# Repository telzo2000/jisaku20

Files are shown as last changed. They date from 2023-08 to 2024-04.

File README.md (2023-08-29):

# jisaku20

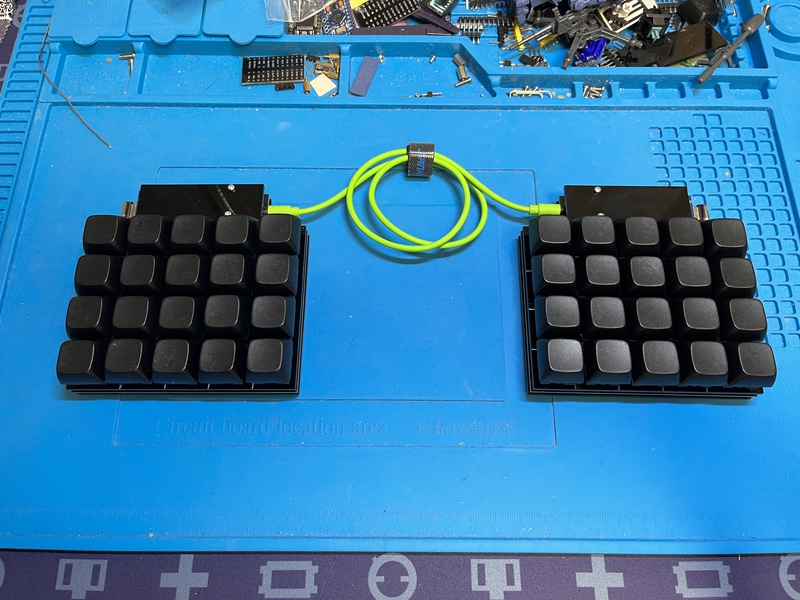
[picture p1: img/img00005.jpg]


jisaku20 is a 4x5 macro pad keyboard.
<br>
jisaku20は４×５のマクロパッドキーボードです。
<br><br>
By connecting jisaku20 and jisaku20_right with a TRRS cable, it becomes a 40-key split keyboard.Call it jisaku20x2.
<br>
jisaku20とjisaku20_rightをTRRSケーブルで繋ぐことにより、40キーの分割キーボードになります。それをjisaku20x2と呼びます。

<br>
<br>

## firmware

https://github.com/telzo2000/jisaku20/tree/main/firmware

## Case(acrylic plate)

https://github.com/telzo2000/jisaku20/tree/main/case_design

## Parts list

### jisaku20

| No. | Patrs | Quantity | remarks | Suppliers | Cost |
|--|--|--|--|--|--|
|番号|名前|数|備考|調達先|参考価格（送料込）|<br>
|1|PCB|1|20key ortho Layout|[elecrow](https://www.elecrow.com)<br>[JLCPCB](https://jlcpcb.com)<br>[ALLPCB](https://www.allpcb.com)|５枚で10〜20ドル|<br>
|2|Switch Plate|1||[elecrow](https://www.elecrow.com)|５枚で20〜30ドル|<br>
|3|Cover Plate|1|↑|↑|↑|<br>
|4|Bottom Plate|1|↑|↑|↑|<br>
|5|pro micro|1||[Talp Keyboard](https://talpkeyboard.net)|800円|
|6|Swith socket<br>スイッチソケット|20|cherry MX互換|[遊舎工房](https://yushakobo.jp)<br>[Talp Keyboard](https://talpkeyboard.net)<br>[Daily Craft Keyboard](https://shop.dailycraft.jp)等|10個で165円程度|
|7|Diode<br>ダイオード|20|リードタイプでもSMDでも可|[遊舎工房](https://yushakobo.jp)<br>[Talp Keyboard](https://talpkeyboard.net)<br>[Daily Craft Keyboard](https://shop.dailycraft.jp)等|100個で220円程度から|
|7|TRRS jack|1||[遊舎工房](https://yushakobo.jp)<br>[Talp Keyboard](https://talpkeyboard.net)<br>|１個55円|<br>
|8|リセット用タクトスイッチ|1||[遊舎工房](https://yushakobo.jp)<br>[Talp Keyboard](https://talpkeyboard.net)<br>|１個11円|<br>

※When using as jisaku20x2, the total number is doubled and a TRRS cable is required.
<br>
※jisaku20x2として使用する場合、すべての個数が２倍となり、さらに、TRRSケーブルが必要となります。
<br><br>
In addition, you will need a USB cable, keycaps, etc.
<br>
この他に、USBケーブル、キーキャップ等が必要です。
<br>

<br>

## Build guide

https://github.com/telzo2000/jisaku20/blob/main/buildguide_for_jisaku20.md

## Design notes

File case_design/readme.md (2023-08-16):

## Note

The case data is 2mm thick and 200mm long x 200mm wide.
<br>
ケースデータは厚み2mm、縦200mm×横200mmのサイズ。
<br>

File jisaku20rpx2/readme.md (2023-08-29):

# jisaku20rpx2

jisaku20rpx2

*A short description of the keyboard/project*

* Keyboard Maintainer: [m.ki](https://github.com/telzo2000)
* Hardware Supported: *The PCBs, controllers supported*
* Hardware Availability: *Links to where you can find this hardware*

Make example for this keyboard (after setting up your build environment):

    make jisaku20rpx2:default

Flashing example for this keyboard:

    make jisaku20rpx2:default:flash

See the [build environment setup](https://docs.qmk.fm/#/getting_started_build_tools) and the [make instructions](https://docs.qmk.fm/#/getting_started_make_guide) for more information. Brand new to QMK? Start with our [Complete Newbs Guide](https://docs.qmk.fm/#/newbs).

## Bootloader

Enter the bootloader in 3 ways:

* **Bootmagic reset**: Hold down the key at (0,0) in the matrix (usually the top left key or Escape) and plug in the keyboard
* **Physical reset button**: Briefly press the button on the back of the PCB - some may have pads you must short instead
* **Keycode in layout**: Press the key mapped to `QK_BOOT` if it is available

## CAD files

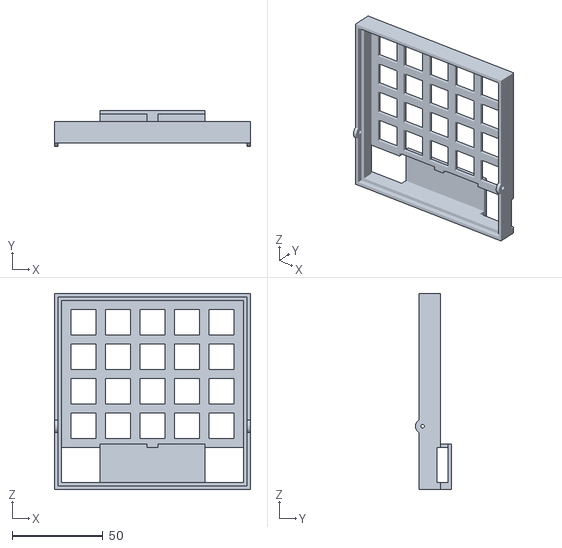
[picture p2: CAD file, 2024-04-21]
case_design/3D_print_case/sakurei_2/jisaku20rp_boxtype_bottomcase v3.stl
108.2 x 20.0 x 108.4

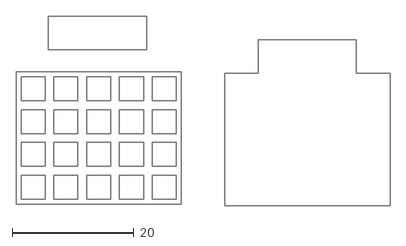
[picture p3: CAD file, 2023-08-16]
case_design/jisaku20_case/jisaku20_case.dxf
61.4 x 31.1

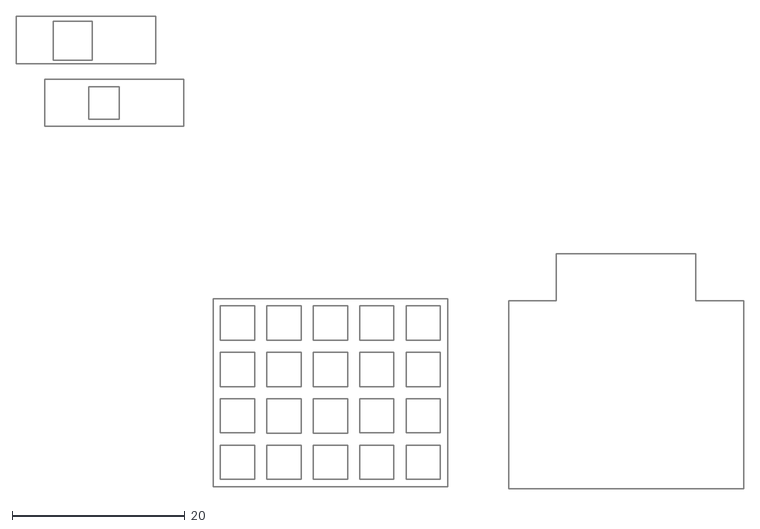
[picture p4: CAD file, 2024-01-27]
case_design/jisaku20_case2/jisaku20_case2.dxf
84.1 x 54.6

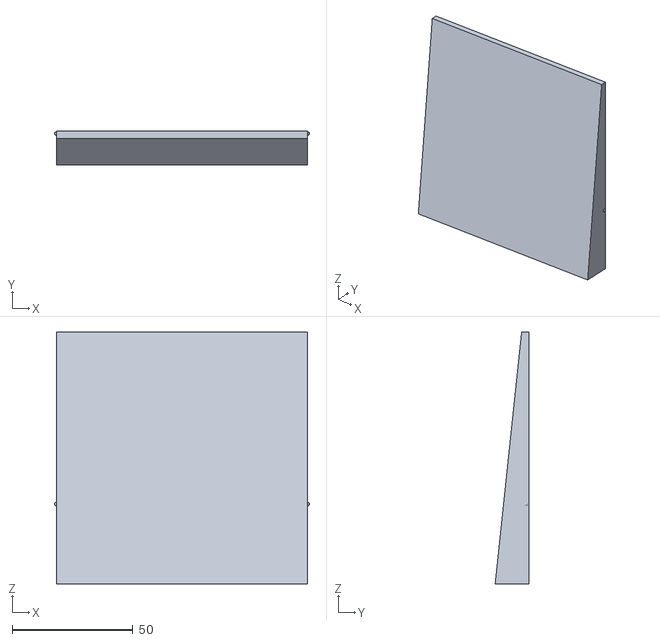
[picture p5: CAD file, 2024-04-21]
case_design/3D_print_case/sakurei_2/jisaku20rp_boxtype_topcase v5.stl
105.7 x 14.0 x 104.4

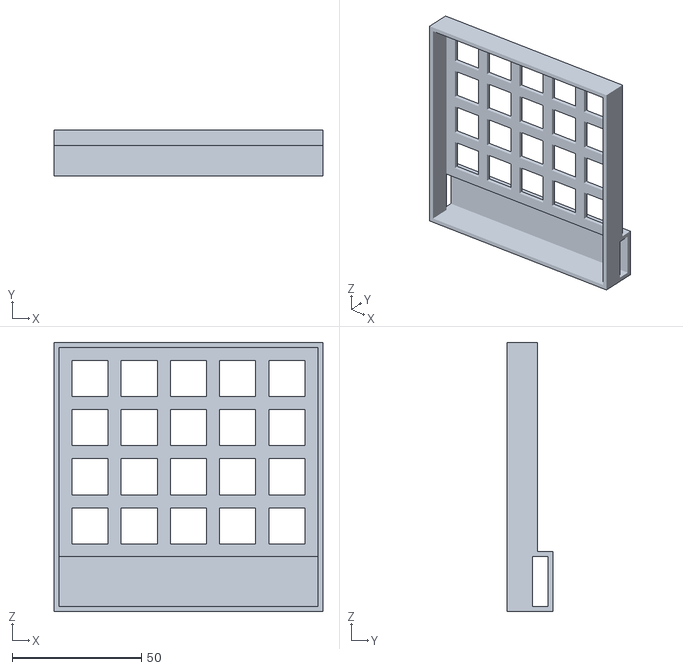
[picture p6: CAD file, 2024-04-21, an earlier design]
case_design/3D_print_case/sakurei_2/jisaku20rp_boxtype_topcase v2.stl
104.2 x 18.0 x 104.4

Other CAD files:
case_design/3D_print_case/sakurei_2/jisaku20rp_boxtype_bottomcase v2.stl

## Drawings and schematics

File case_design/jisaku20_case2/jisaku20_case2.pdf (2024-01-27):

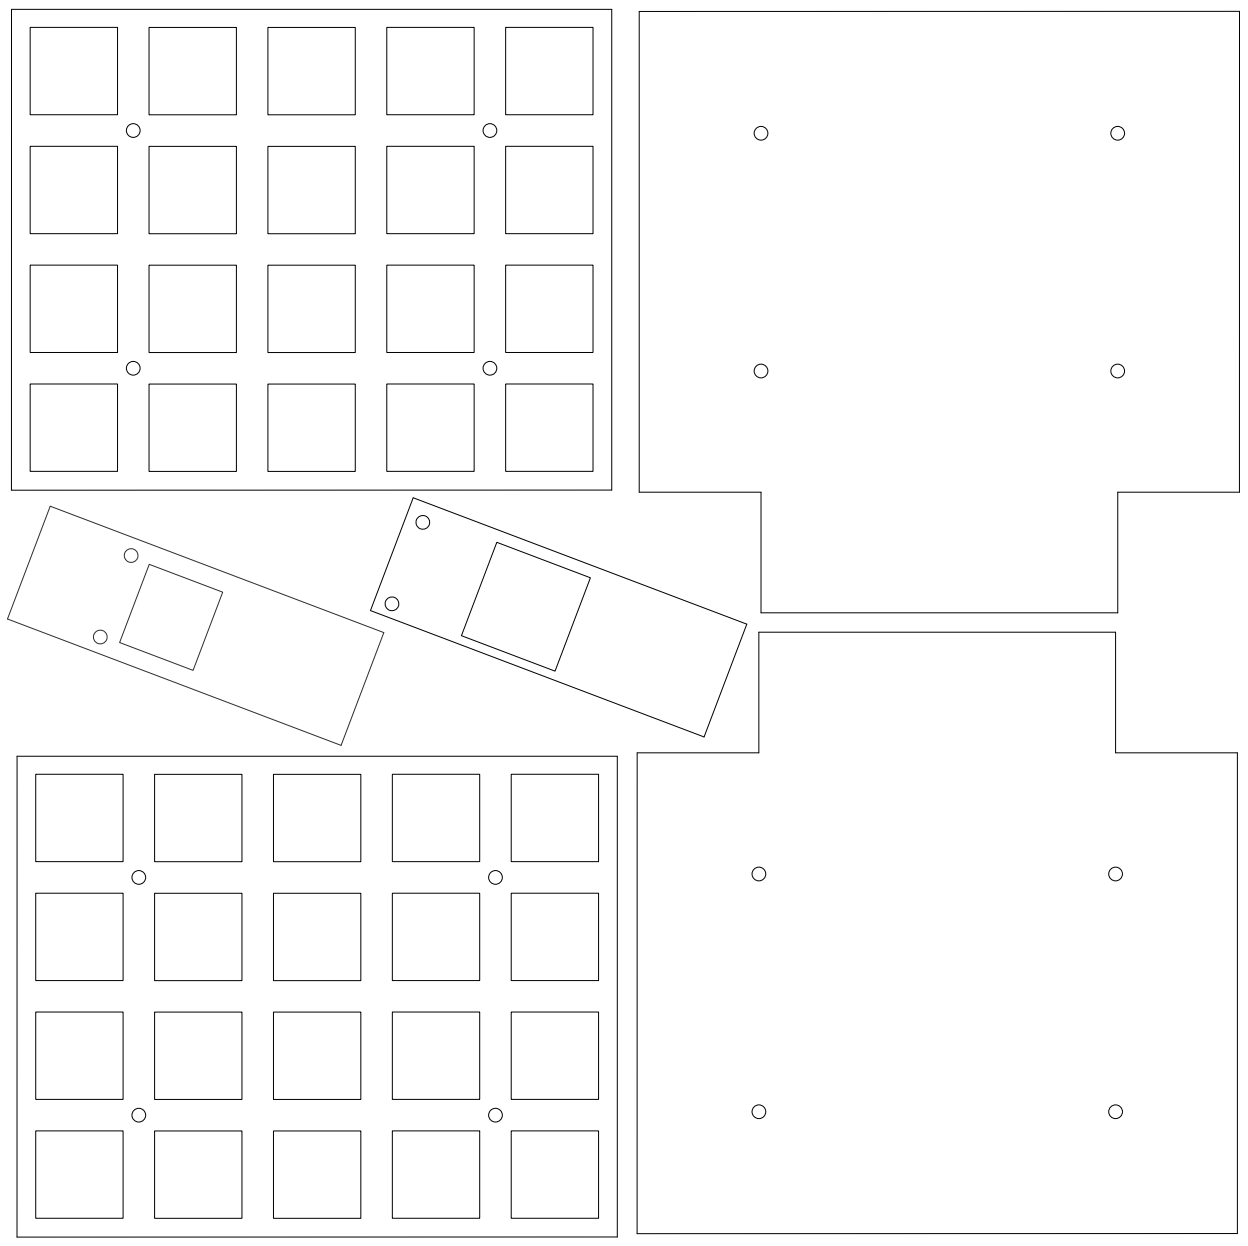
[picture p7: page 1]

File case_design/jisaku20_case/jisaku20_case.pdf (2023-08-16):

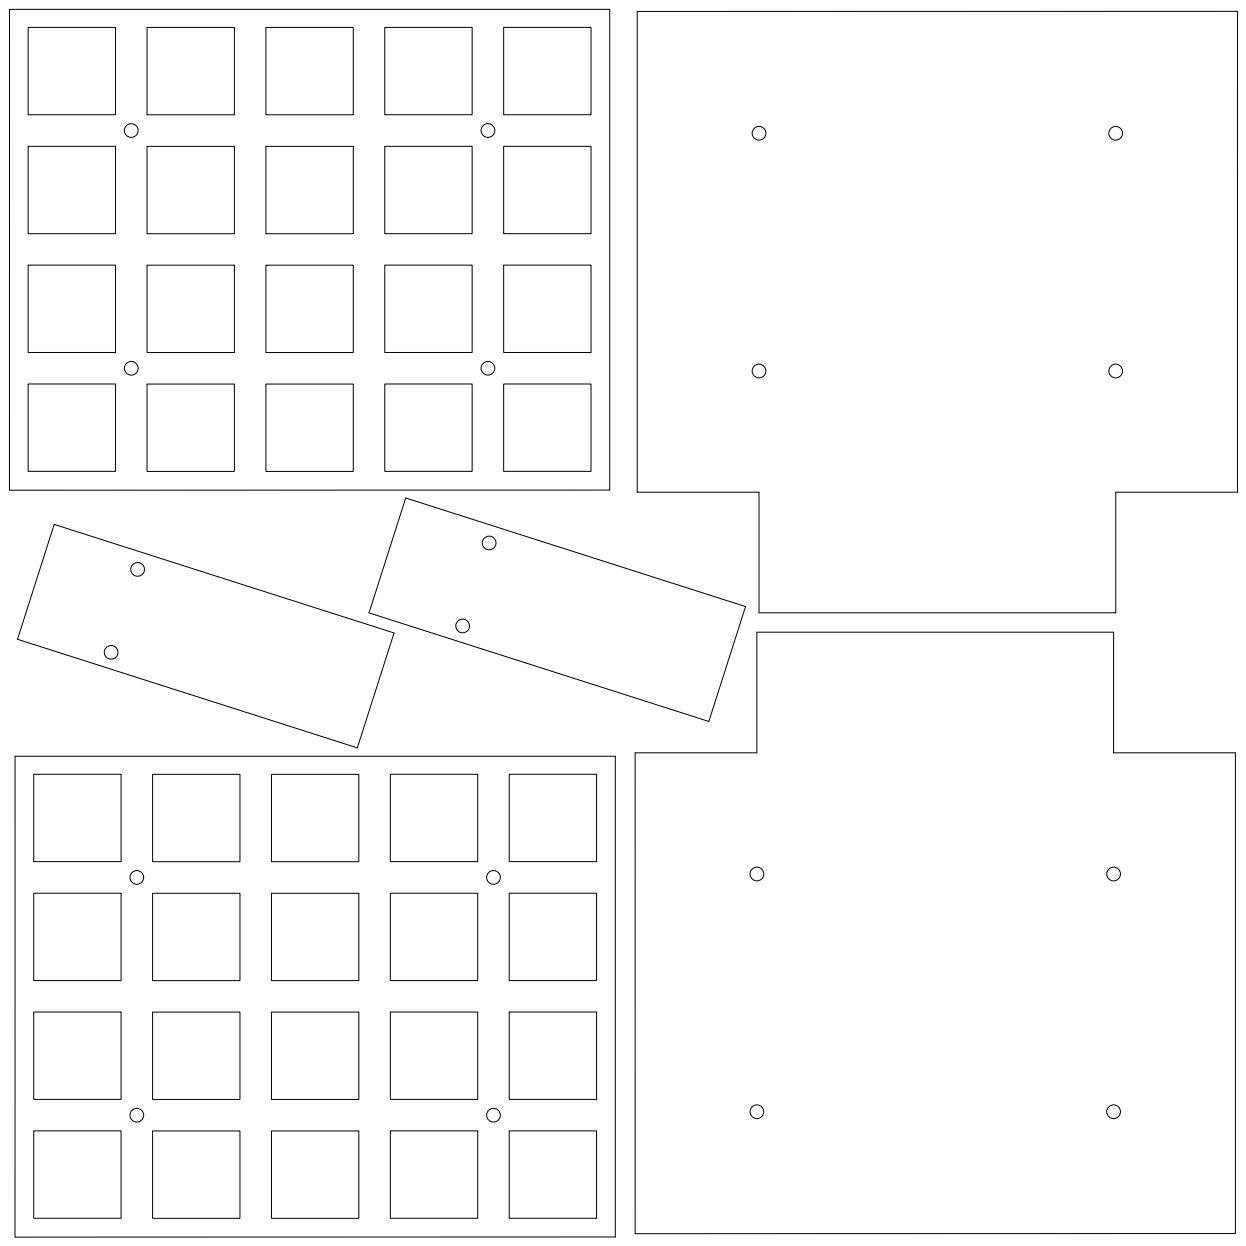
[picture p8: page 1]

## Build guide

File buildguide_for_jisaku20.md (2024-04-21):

# Build guide

## Firmware

###  QMK_FIRMWARE
[Here](https://github.com/telzo2000/jisaku20/tree/main/firmware)

<br>

参考<br>

https://github.com/telzo2000/Hello_keyboard/blob/main/readme_about_firmware.md

<br>

## Build 

### 1 Parts check

jisaku20 and jisaku20_right have a front side and a back side.
<br>
jisaku20及びjisaku20_rightには表面と裏面があります。
<br>

Front side

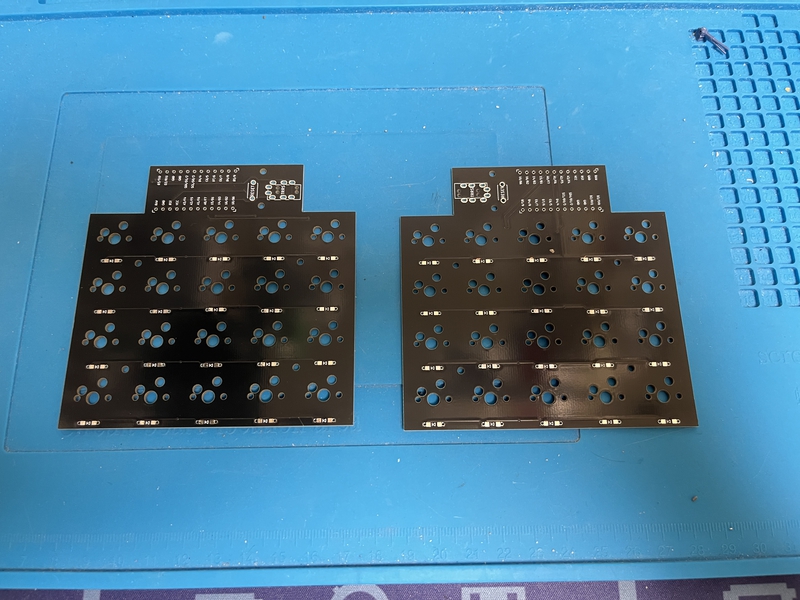
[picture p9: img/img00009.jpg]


Back side

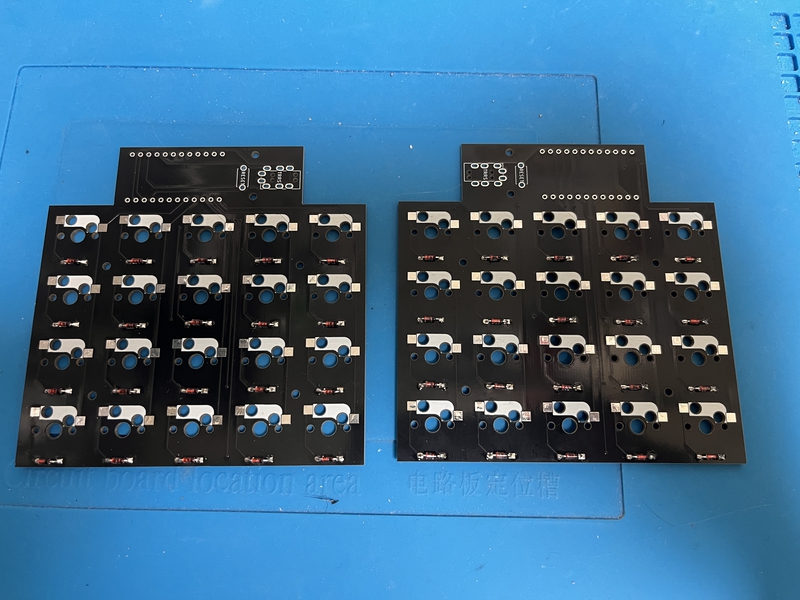
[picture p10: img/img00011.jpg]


<br>

### 2 Diode soldering

Note! "The diode's silk is wrong and sticks to the surface."
<br>
注意！　ダイオードのシルクが間違って、表面に付いています。
<br><br>

Solder the diodes to the back of each of the left and right.
<br>
左右それぞれの裏面にダイオードのハンダ付けをします。
<br>

There are lead type and SMD diodes.
<br>
ダイオードはリードタイプか、SMDがあります。
<br>
Here, we will explain the lead type soldering.
<br>
ここでは、リードタイプのハンダ付けの説明をします。
<br>

Use a lead bender to bend the legs of the diode.
<br>
リードベンダーを使い、ダイオードの足を曲げます。
<br>
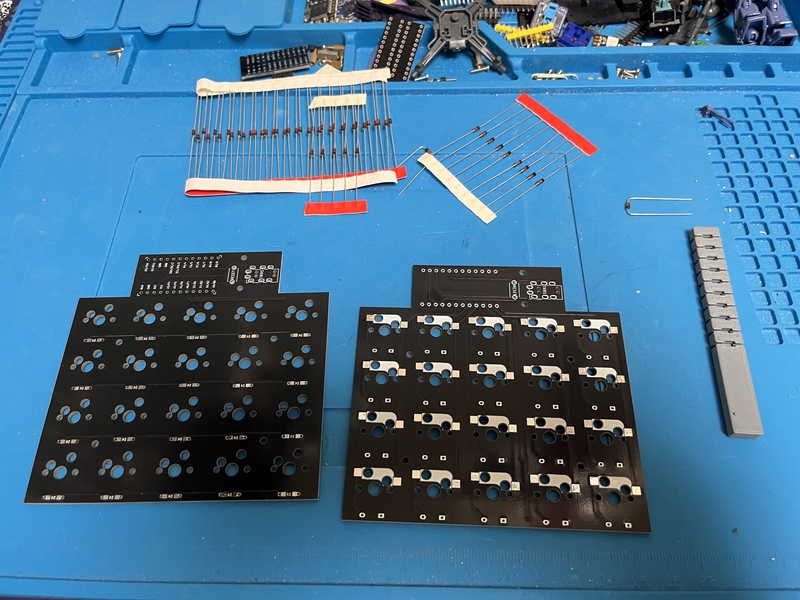
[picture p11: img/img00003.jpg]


Insert the diode into the board.
<br>
ダイオードを基板に挿しこみます。
<br>

Please pay attention to the orientation of the diode.
<br>
ダイオードの向きに注意してください。
<br>
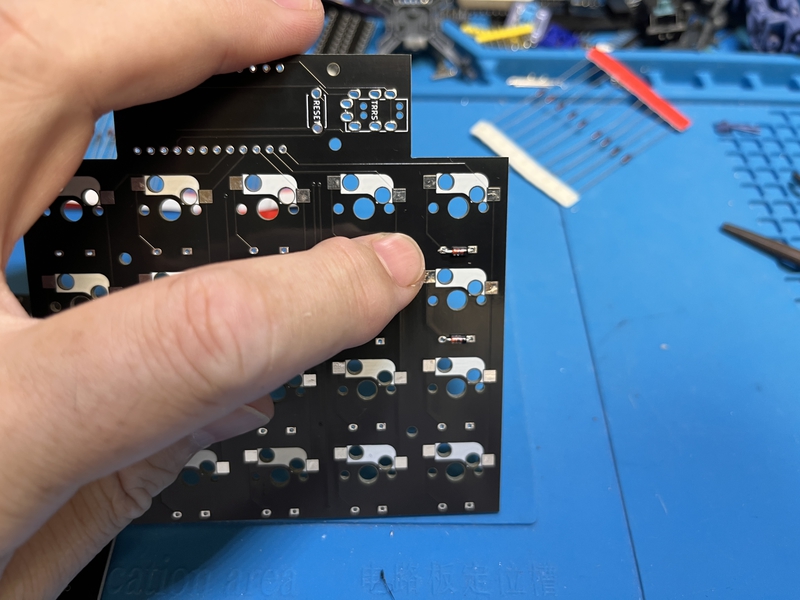
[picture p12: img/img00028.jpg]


Secure the diode with masking tape, then face up.
<br>
マスキングテープでダイオードを固定してから、表面を上にします。
<br>

Solder the protruding legs.
<br>
はみ出ている足部分に、ハンダ付けをします。
<br>
After soldering, use nippers to cut off the protruding legs.
<br>
はんだ付けが終わったら、はみ出ている足をニッパーで切り取ってください。
<br>


[８倍速　Diodeハンダ付け動画](https://youtu.be/Yaodh2-XxV4)

<br>
<br>

### 3 Soldering switch sockets

Solder the switch sockets on the back side.
<br>
裏面にスイッチソケットのハンダ付けをします。
<br>
Hold a little solder on the terminals.
<br>
端子に少しハンダを持ってください。
<br>

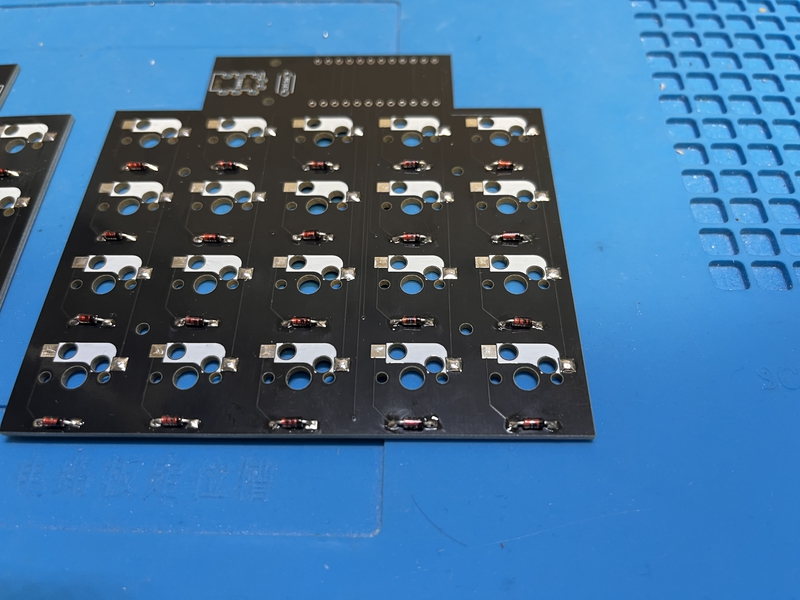
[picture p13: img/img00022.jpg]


Place the switch so that the silk of the switch socket is hidden. Then, warm the solder that you just poured with a soldering iron.
<br>
スイッチソケットのシルクが隠れるようにスイッチを載せてください。そして、先ほど盛ったハンダをハンダゴテで温めてください。
<br>

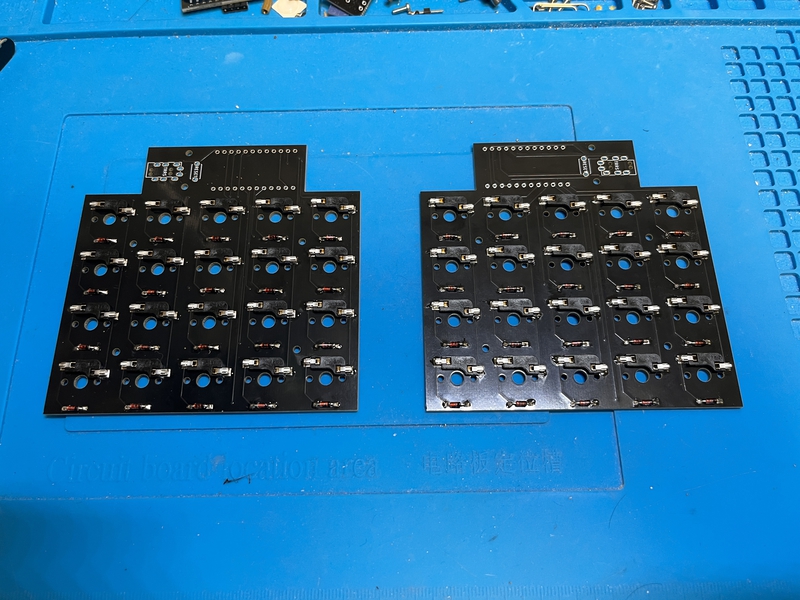
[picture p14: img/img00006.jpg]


Place the switch socket and fix it with a warm soldering iron while melting the solder.
<br>
スイッチソケットを乗せて、温めたハンダゴテで、ハンダを溶かしながら、固定します。
<br>
You can make it easier by working while holding it with tweezers.
<br>
ピンセットで押さえながら、作業をすると楽にできます。
<br>

[８倍速　Switch socketハンダ付け動画](https://youtu.be/E__mHvmIXQo)

<br><br>

### 4 Soldering reset switch & TRRS jack 

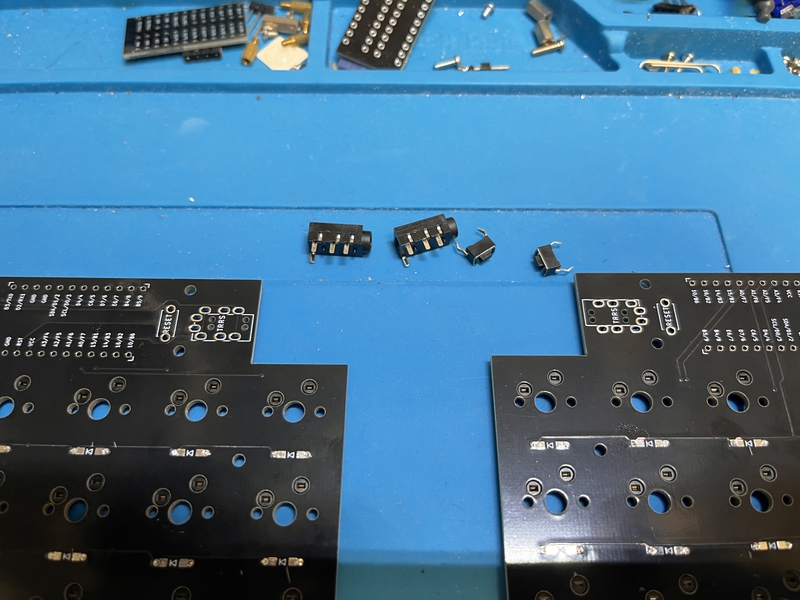
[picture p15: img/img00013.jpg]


Insert the reset switch on the surface.
<br>
表面にリセットスイッチを挿しこみます。
<br>
Solder the legs of the reset switch from the back.
<br>
裏面からリセットスイッチの足をハンダ付けします。
<br>
Solder the TRRS jack in the same way near the reset switch.
<br>
TRRSジャックは、リセットスイッチの近くに同じようにハンダ付けします。
<br>
Insert the left and right TRRS jacks from the front side and solder from the back side.
<br>
TRRSジャックは左右１箇所ずつ、表面から差し込み、裏面からはんだ付けをしてください。
<br>
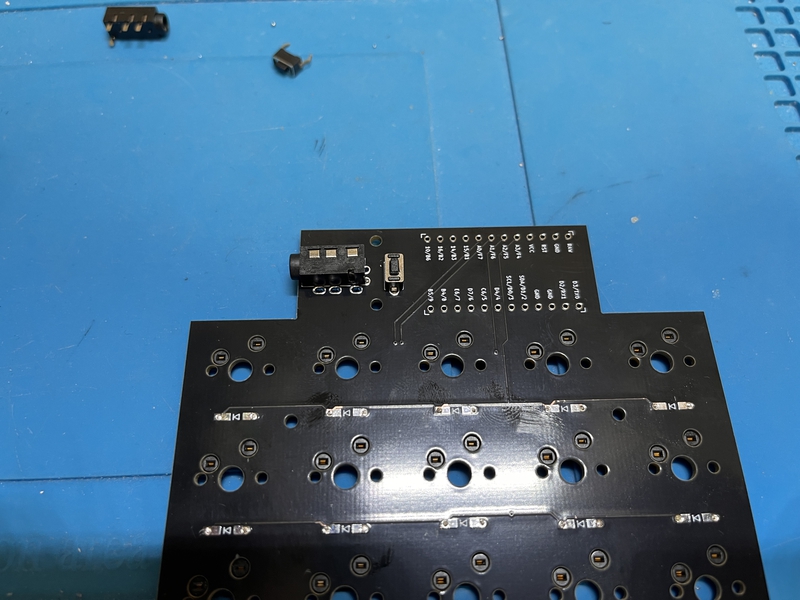
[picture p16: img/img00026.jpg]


[８倍速　Reset switch,TRRS jackハンダ付け動画](https://youtu.be/3gEbExaOAv4)

<br><br>

### 5　Pro micro 

Use the conthrough to fix the pro micro with the side with the parts facing down.
<br>
pro microの部品のある面を下向きに、コンスルーを使い、固定してください。
<br>

Pay attention to the orientation of the conthrough.
<br>
コンスルーの向きに注意してください。
<br>

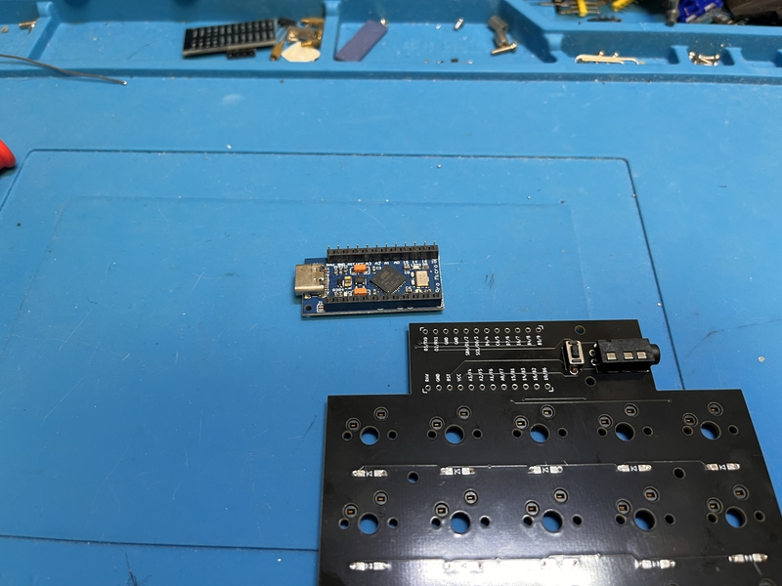
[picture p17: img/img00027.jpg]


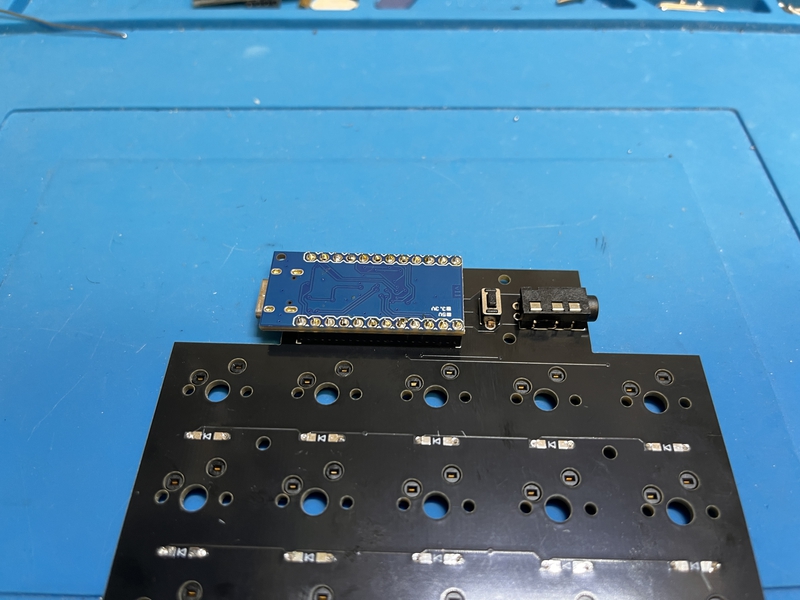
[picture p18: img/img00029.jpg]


<br>

### 6　Test

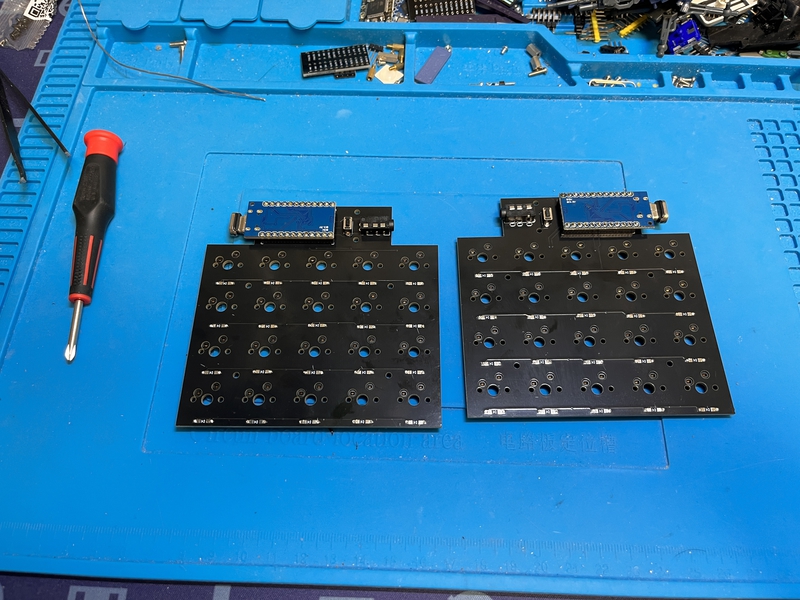
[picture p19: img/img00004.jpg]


Please write the firmware and check the operation.
<br>
ファームウェアを書き込んで、動作確認をしてください。
<br>

Install a switch or measure continuity with tweezers, etc.
<br>
スイッチを取り付けるか、ピンセット等で導通をはかるかを行います。
<br>

<br>

### QMK_FIRMWARE
[Here](https://github.com/telzo2000/jisaku20/tree/main/firmware)

<br>

### 7 Installation of switch plate（cherry MX switch）

Prepare a switch plate, M2 spacer 3 mm（x８）, and M2 screw 8 mm（x４）.
<br>
スイッチプレート、M2スペーサー３mm（８本）、M2ネジ８mm（４本）を用意します。
<br>
Fix the screws in 4 places.
<br>
ネジを４箇所、固定します。
<br>
Insert the switch plate into the screw and fix it with a spacer.
<br>
ネジはスイッチプレートをさしこみ、スペーサーで固定します。
<br>

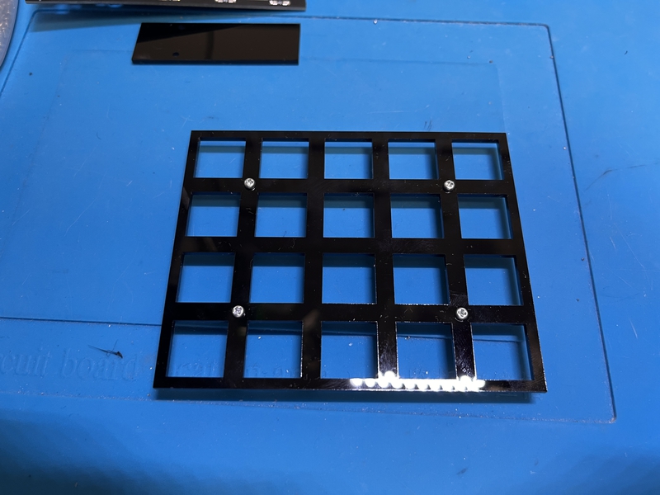
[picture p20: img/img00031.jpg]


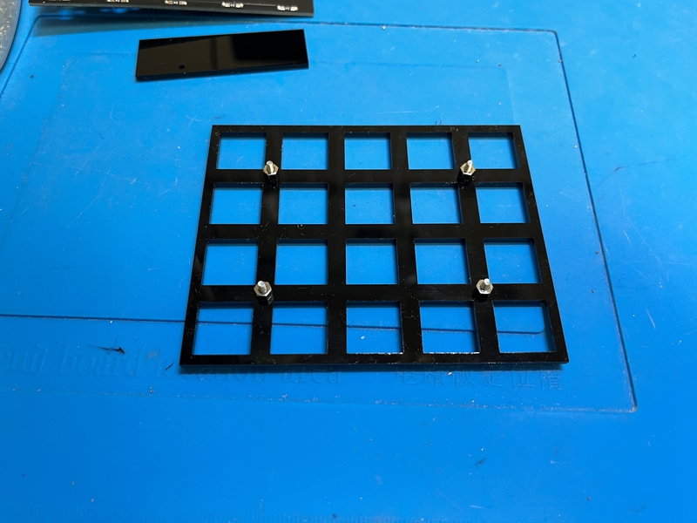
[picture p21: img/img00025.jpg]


Next, insert the switch plate into the PCB and secure it with a spacer on the back of the PCB.
<br>
次に、スイッチプレートをPCBにさしこみ、PCBの裏面でスペーサーで固定します。
<br>
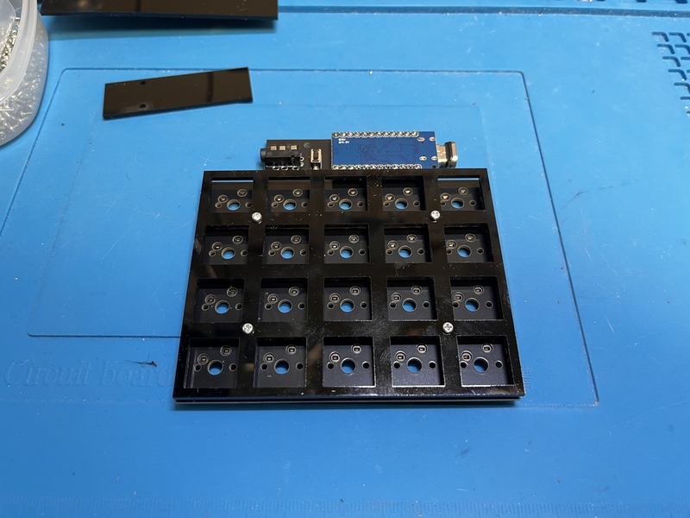
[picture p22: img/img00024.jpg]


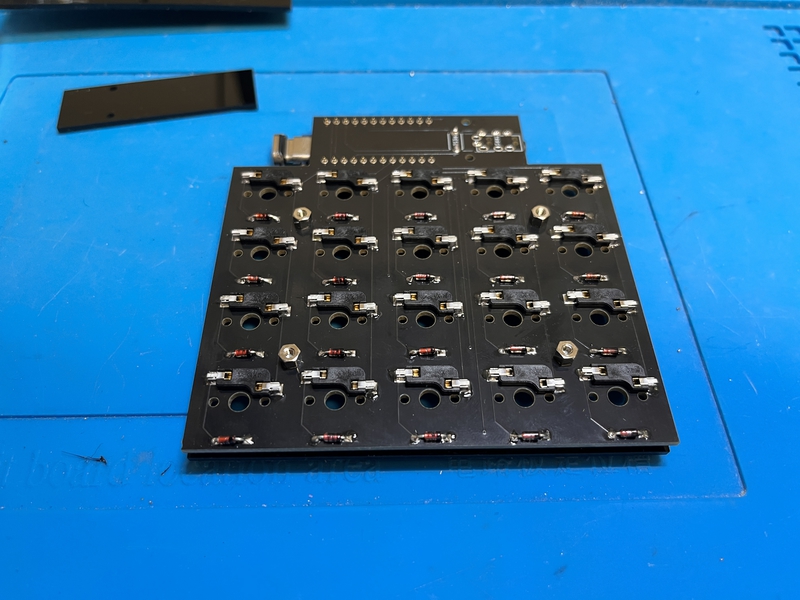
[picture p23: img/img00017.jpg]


### 8 Installation of cover plate

Prepare a cover plate, M2 spacer 8mm（x2）, and M2 screw 3mm（x4）.
<br>
カバープレート、M2スペーサー8mm（2個）、M2ネジ3mm（4本）を用意します。
<br>
Screw the spacer to the cover plate in the same orientation.
<br>
カバープレートに同じ向きで、スペーサーをネジで固定します。
<br>
Then use the remaining screws to attach the cover plate to the PCB.
<br>
次に、残りのネジを使い、カバープレートをPCBに取り付けます。
<br>
There is an orientation of the cover plate, so it is good to check it once before starting work.
<br>
カバープレートの向きがあり、作業前に一度、重ねて確認すると良いです。
<br>
<br>

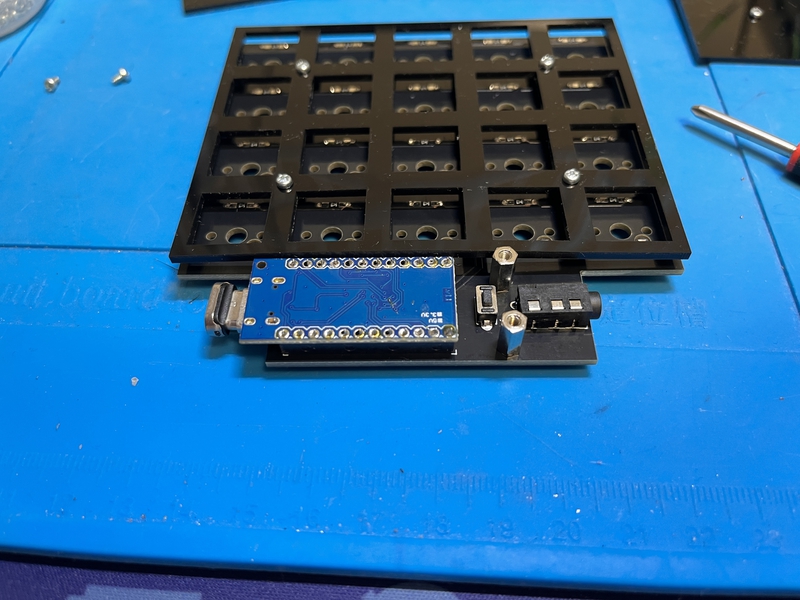
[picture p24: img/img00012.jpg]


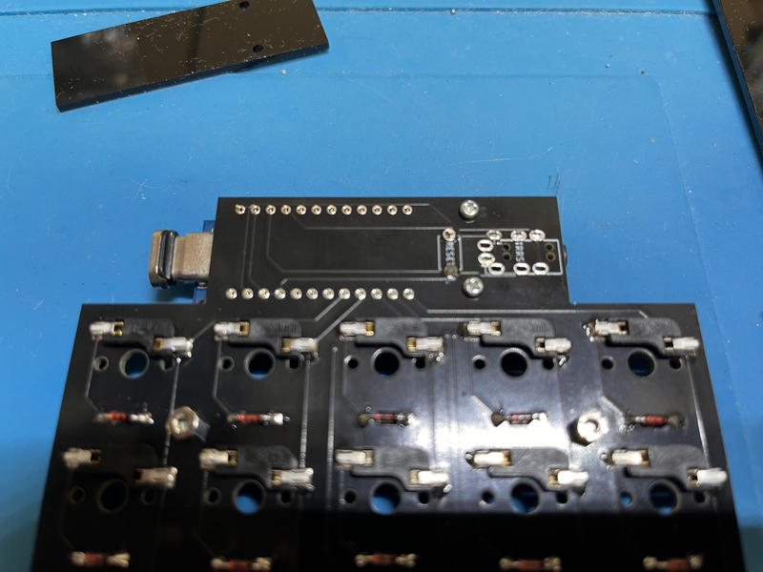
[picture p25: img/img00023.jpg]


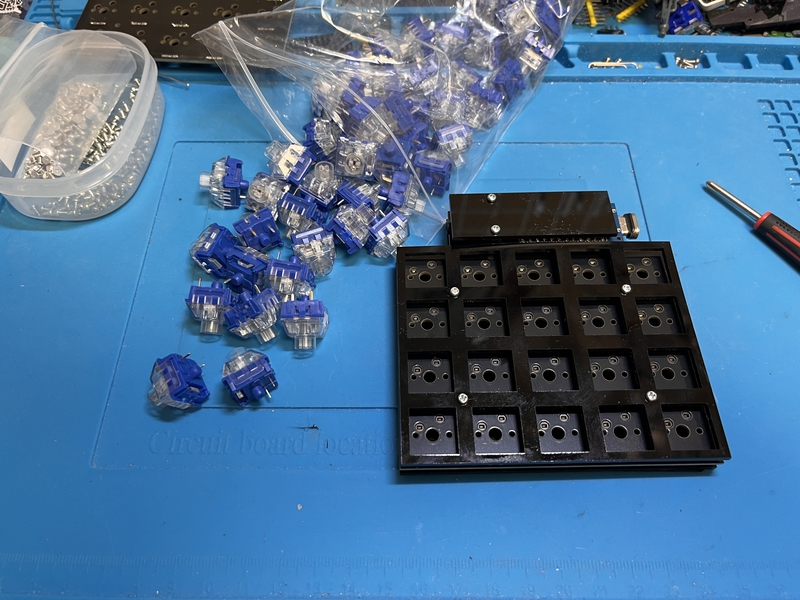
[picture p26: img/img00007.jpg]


### 9 Installation of bottom plate 

Prepare the bottom plate and M2 ３mm screws（x４）.
<br>
ボトムプレート、M２ネジ３mm（４本）を用意します。
<br>
Place the bottom plate according to the spacer on the back of the PCB and fix it with screws.
<br>
PCB裏面にあるスペーサーに合わせて、ボトムプレートをのせて、ネジで固定します。
<br>
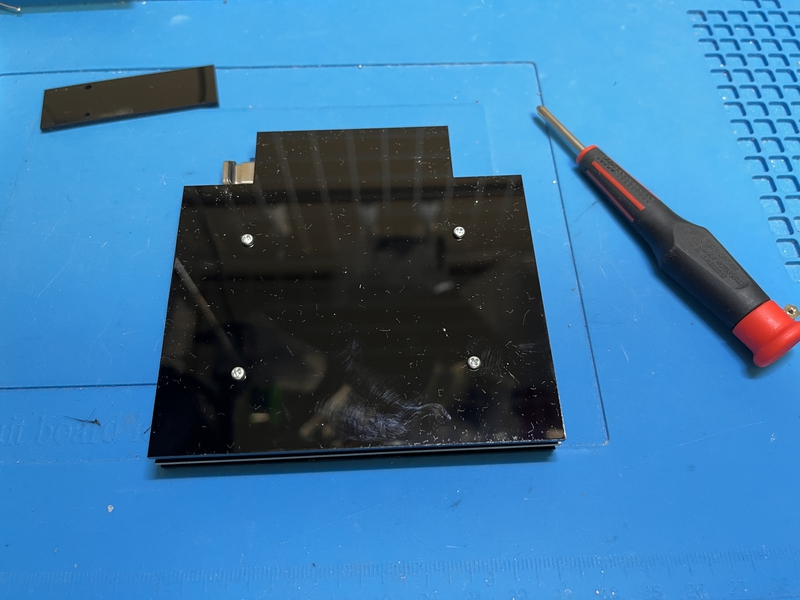
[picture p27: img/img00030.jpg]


### 10 Installation of switch sockets and keycaps　

Insert your favorite switch socket. Be careful not to bend the lead when inserting it.
<br>
お気に入りのスイッチソケットを挿入してください。差し込む際リードが曲がらないように注意してください。
<br>
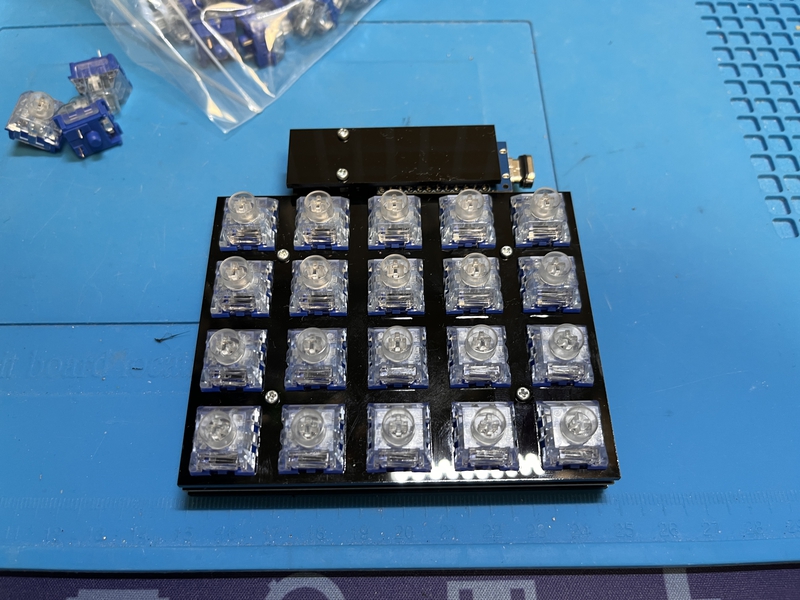
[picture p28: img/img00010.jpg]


Then insert your favorite keycaps.
<br>
次に、お気に入りのキーキャップを挿入してください。
<br>
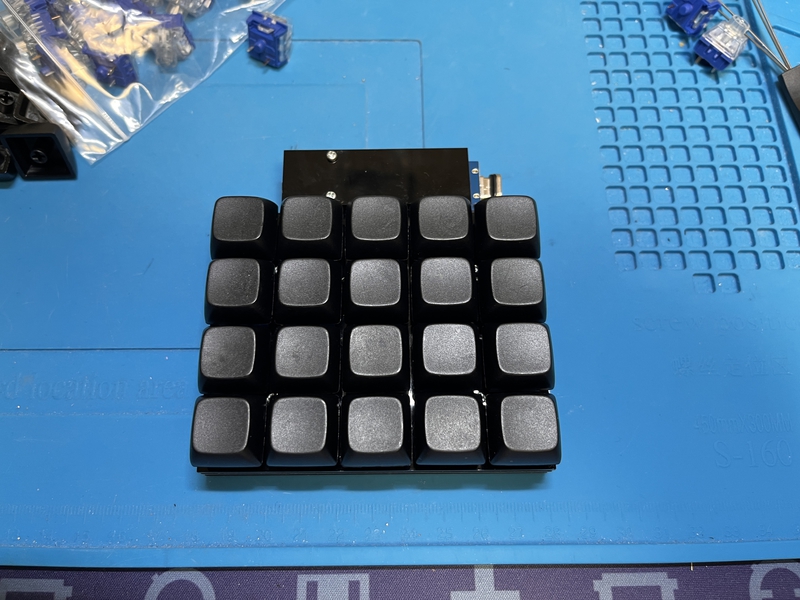
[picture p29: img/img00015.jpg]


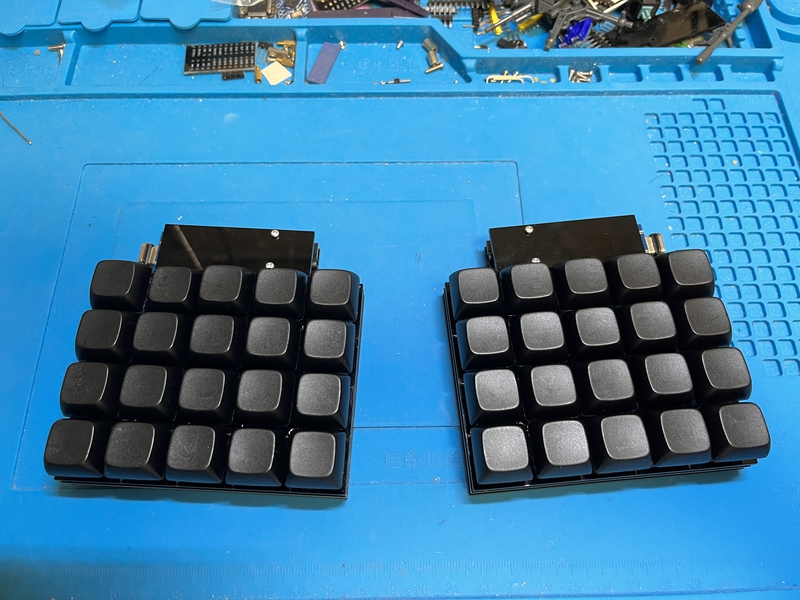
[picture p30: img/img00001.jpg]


Prepare a TRRS cable or a USB cable.
<br>
TRRSケーブルやUSBケーブルを用意しましょう。
<br>
<br>
Have a fun selfmade keyboard life!
<br>
楽しい自作キーボード生活を!



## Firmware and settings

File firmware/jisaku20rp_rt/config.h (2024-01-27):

// Copyright 2023 m.ki (@telzo2000)
// SPDX-License-Identifier: GPL-2.0-or-later

#pragma once

/*
 * Feature disable options
 *  These options are also useful to firmware size reduction.
 */

/* disable debug print */
//#define NO_DEBUG

/* disable print */
//#define NO_PRINT

/* disable action features */
//#define NO_ACTION_LAYER
//#define NO_ACTION_TAPPING
//#define NO_ACTION_ONESHOT
#define I2C1_SCL_PIN GP27
#define I2C1_SDA_PIN GP26
#define I2C_DRIVER I2CD1
#define POINTING_DEVICE_ROTATION_180
#define PIMORONI_TRACKBALL_SCALE 10

#define MASTER_RIGHT
#define SOFT_SERIAL_PIN GP0
#define ENCODERS_PAD_A { GP5 }
#define ENCODERS_PAD_B { GP6 }
 
#define MATRIX_ROW_PINS_RIGHT {GP9, GP10, GP11, GP12}
#define MATRIX_COL_PINS_RIGHT {GP15, GP14, GP13, GP8,GP7}

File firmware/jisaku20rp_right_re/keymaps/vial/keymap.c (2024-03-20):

#include QMK_KEYBOARD_H

const uint16_t PROGMEM keymaps[][MATRIX_ROWS][MATRIX_COLS] = {
    
    [0] = LAYOUT_ortho_4x10(
        KC_Q,   KC_W,   KC_E,   KC_R,   KC_T,   KC_Y,   KC_U,   KC_I,   KC_O,   KC_P,
        KC_A,   KC_S,   KC_D,   KC_F,   KC_G,   KC_H,   KC_J,   KC_K,   KC_L,   KC_ENT,
        KC_Z,   KC_X,   KC_C,   KC_V,   KC_B,   KC_N,   KC_M,   KC_COMM,KC_DOT, KC_RSFT,
        TG(1), KC_TAB, KC_LCTL,KC_LGUI,LT(1,KC_SPC), KC_LEFT,KC_DOWN,KC_UP,KC_RIGHT, KC_BSPC,
        KC_1
    ),
    [1] = LAYOUT_ortho_4x10(
        KC_1,   KC_2,   KC_3,   KC_4,   KC_5,   KC_6,   KC_7,   KC_8,   KC_9,   KC_0,
        KC_A,   KC_S,   KC_D,   KC_F,   KC_G,   KC_H,   KC_J,   KC_K,   KC_L,   KC_ENT,
        KC_Z,   KC_X,   KC_C,   KC_V,   KC_B,   KC_N,   KC_M,   KC_COMM,KC_DOT, KC_RSFT,
        KC_ESC, KC_TAB, KC_LCTL,KC_LGUI,KC_SPC, KC_LEFT,KC_DOWN,KC_UP,KC_RIGHT, KC_BSPC,
        KC_2
    ),
        [2] = LAYOUT_ortho_4x10(
        KC_Q,   KC_W,   KC_E,   KC_R,   KC_T,   KC_Y,   KC_U,   KC_I,   KC_O,   KC_P,
        KC_A,   KC_S,   KC_D,   KC_F,   KC_G,   KC_H,   KC_J,   KC_K,   KC_L,   KC_ENT,
        KC_Z,   KC_X,   KC_C,   KC_V,   KC_B,   KC_N,   KC_M,   KC_COMM,KC_DOT, KC_RSFT,
        KC_ESC, KC_TAB, KC_LCTL,KC_LGUI,KC_SPC, KC_LEFT,KC_DOWN,KC_UP,KC_RIGHT, KC_BSPC,
        KC_1
    ),
        [3] = LAYOUT_ortho_4x10(
        KC_Q,   KC_W,   KC_E,   KC_R,   KC_T,   KC_Y,   KC_U,   KC_I,   KC_O,   KC_P,
        KC_A,   KC_S,   KC_D,   KC_F,   KC_G,   KC_H,   KC_J,   KC_K,   KC_L,   KC_ENT,
        KC_Z,   KC_X,   KC_C,   KC_V,   KC_B,   KC_N,   KC_M,   KC_COMM,KC_DOT, KC_RSFT,
        KC_ESC, KC_TAB, KC_LCTL,KC_LGUI,KC_SPC, KC_LEFT,KC_DOWN,KC_UP,KC_RIGHT, KC_BSPC,
        KC_1
    )

};

#if defined(ENCODER_MAP_ENABLE)
const uint16_t PROGMEM encoder_map[][NUM_ENCODERS][2] = {
    [0] = { ENCODER_CCW_CW(KC_MS_UP, KC_MS_DOWN)},
    [1] = { ENCODER_CCW_CW(KC_MS_RIGHT, KC_MS_LEFT)},
    [2] = { ENCODER_CCW_CW(KC_A, KC_B)},
    [3] = { ENCODER_CCW_CW(KC_C, KC_D)},
};
#endif
